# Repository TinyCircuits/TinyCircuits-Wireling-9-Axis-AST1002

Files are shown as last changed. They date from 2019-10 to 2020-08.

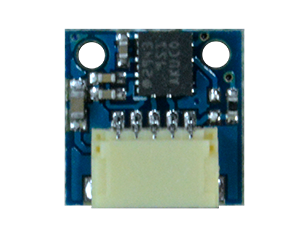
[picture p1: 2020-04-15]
images/AST1002-Learn-Photo-01.png

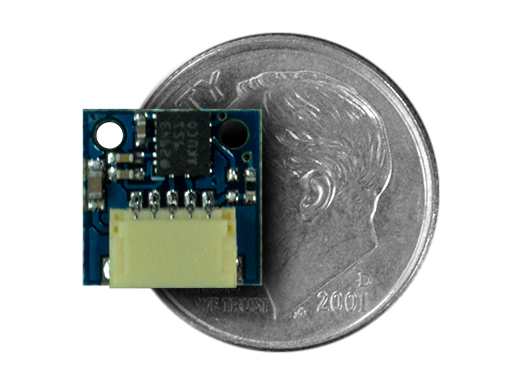
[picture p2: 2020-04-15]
images/AST1002-Product-Photo-03.png

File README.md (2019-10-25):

# TinyCircuits Wireling 9-Axis
# AST1002 Rev1

The design files are located under design_files/ for the TinyCircuits AST1002 Rev 1 PCB. This is a Wireling board which measures 9 degrees of freedom (9DOF) and features the ST LSM9DS1 - a system-in-package featuring a 3D digital linear acceleration sensor, a 3D digital angular rate sensor, and a 3D digital magnetic sensor.

Format is in Cadsoft Eagle format - Eagle version 6.2 was used for the original design.

For more infomation on this, check out the product page at TinyCircuits.com

# License:

Design by TinyCircuits.
All design files are released under the Creative Commons Attribution Share-Alike 3.0 License, see the following link for details: http://creativecommons.org/licenses/by-sa/3.0

All text above must be included in any redistribution or derived design

This project uses designs and concepts developed as part of the Arduino project and the LilyPad project.  The TinyCircuits design files themselves (schematics, PCB and libraries) are not directly derived from these works' design files and have been created new, however the concepts and basic architecture behind the TinyDuino and TinyLily products are derived and we thank the hard work of the organizations below for their contributions to open-source hardware:
  
Original Arduino Uno Design by Team Arduino

LilyPad Arduino Design by Leah Buechley and Sparkfun Electronics

Please support the open-source hardware community

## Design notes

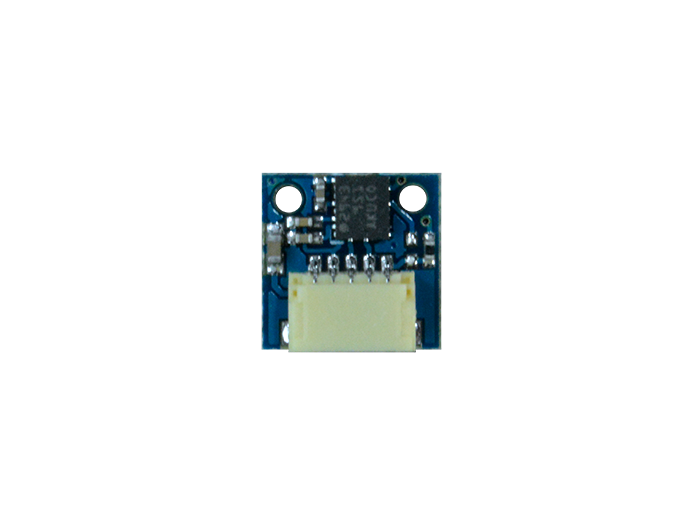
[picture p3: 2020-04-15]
images/AST1002-Product-Photo-01.png

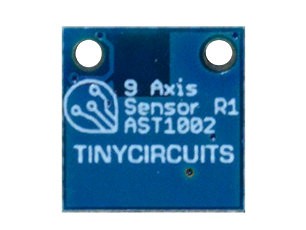
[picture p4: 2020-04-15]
images/AST1002-Learn-Photo-02.png

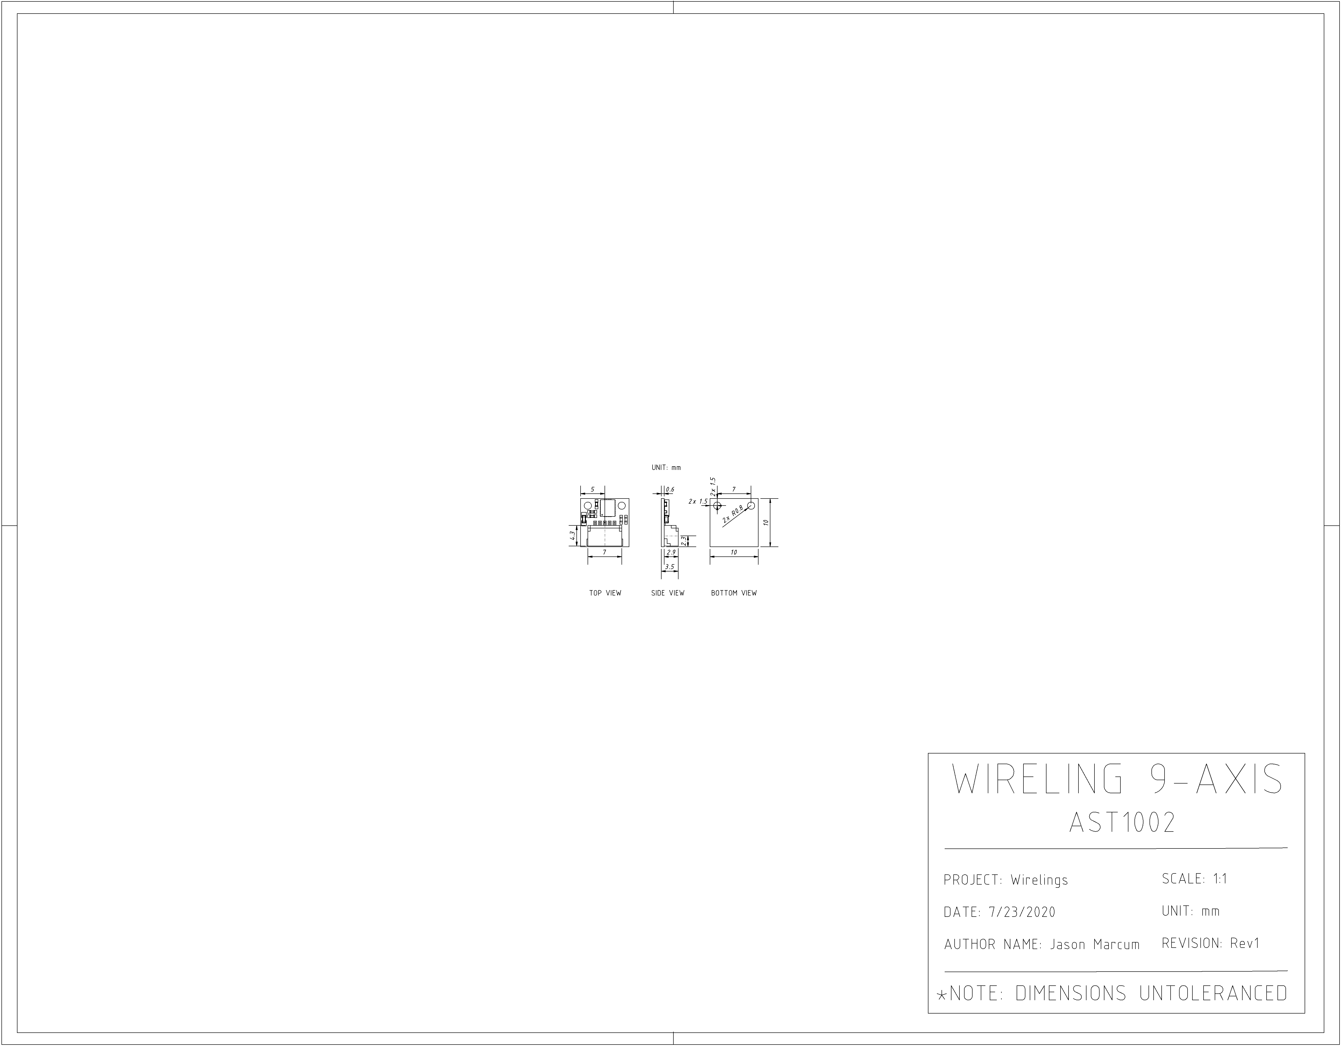
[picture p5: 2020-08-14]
cad/Wireling_9AXIS_AST1002_REV1-DETAILED_DRAWING-PNG.png

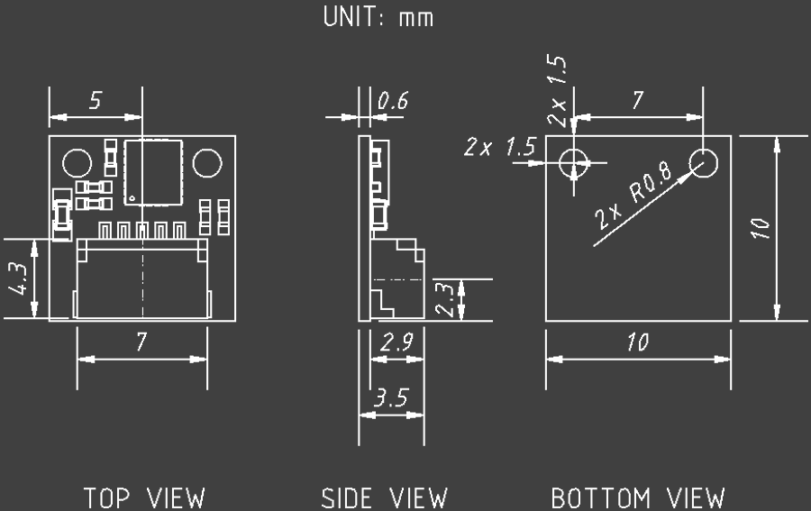
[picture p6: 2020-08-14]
cad/Wireling_9AXIS_AST1002_REV1-DETAILED_DRAWING_COMPACT-PNG.png

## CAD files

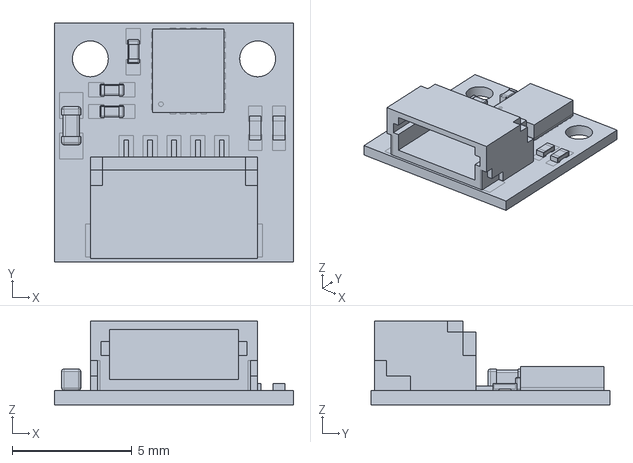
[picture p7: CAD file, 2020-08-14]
cad/Wireling_9AXIS_AST1002_REV1-IGES.iges
10.0 x 10.0 x 3.50 mm

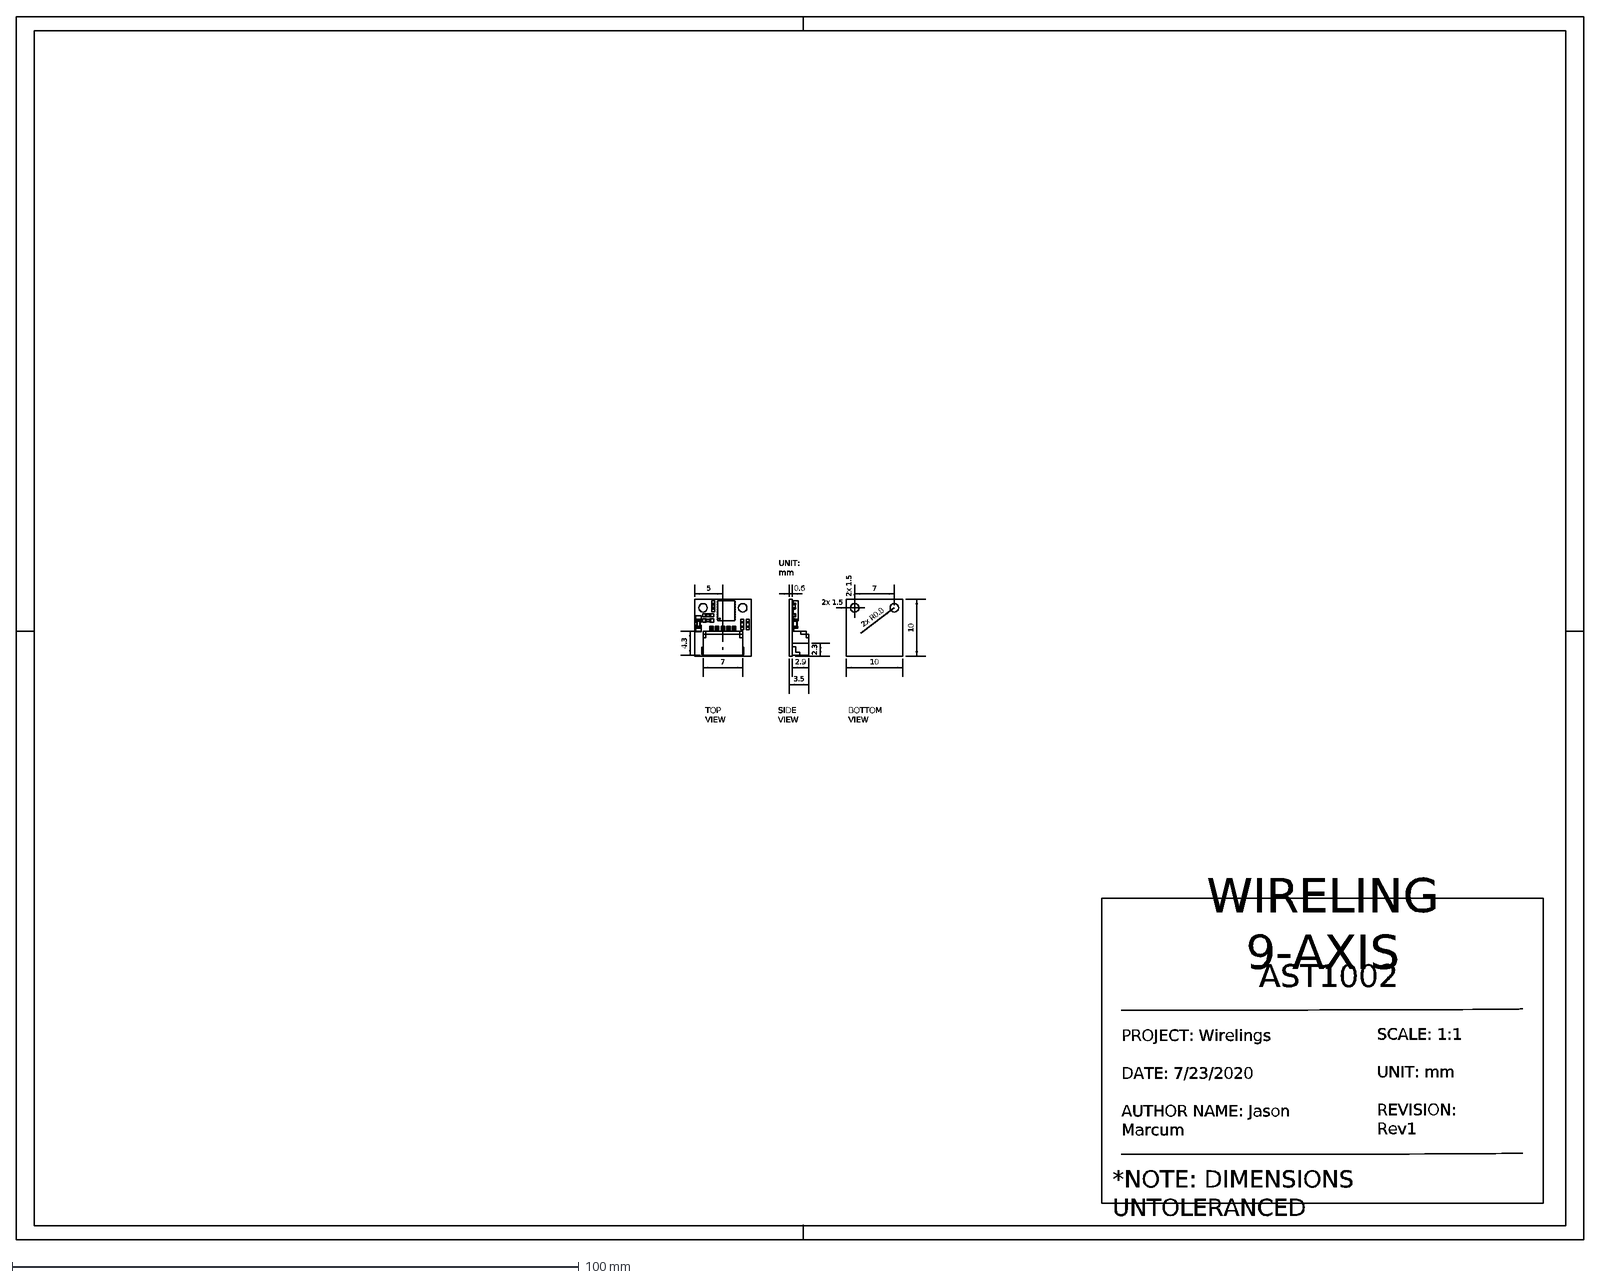
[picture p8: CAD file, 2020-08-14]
cad/Wireling_9AXIS_AST1002_REV1-DETAILED_DRAWING-DXF.dxf
*NOTE: DIMENSIONS UNTOLERANCED
SCALE: 1:1 UNIT: mm REVISION: Rev1
TOP VIEW
BOTTOM VIEW
SIDE VIEW
UNIT: mm
7
4.3
5
2.9
3.5
2.3
0.6
2x 1.5
2x R0.8
10
WIRELING 9-AXIS
AST1002
PROJECT: Wirelings DATE: 7/23/2020 AUTHOR NAME: Jason Marcum

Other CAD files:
cad/Wireling_9AXIS_AST1002_REV1-STL.stl
cad/Wireling_9AXIS_AST1002_REV1-STEP.step

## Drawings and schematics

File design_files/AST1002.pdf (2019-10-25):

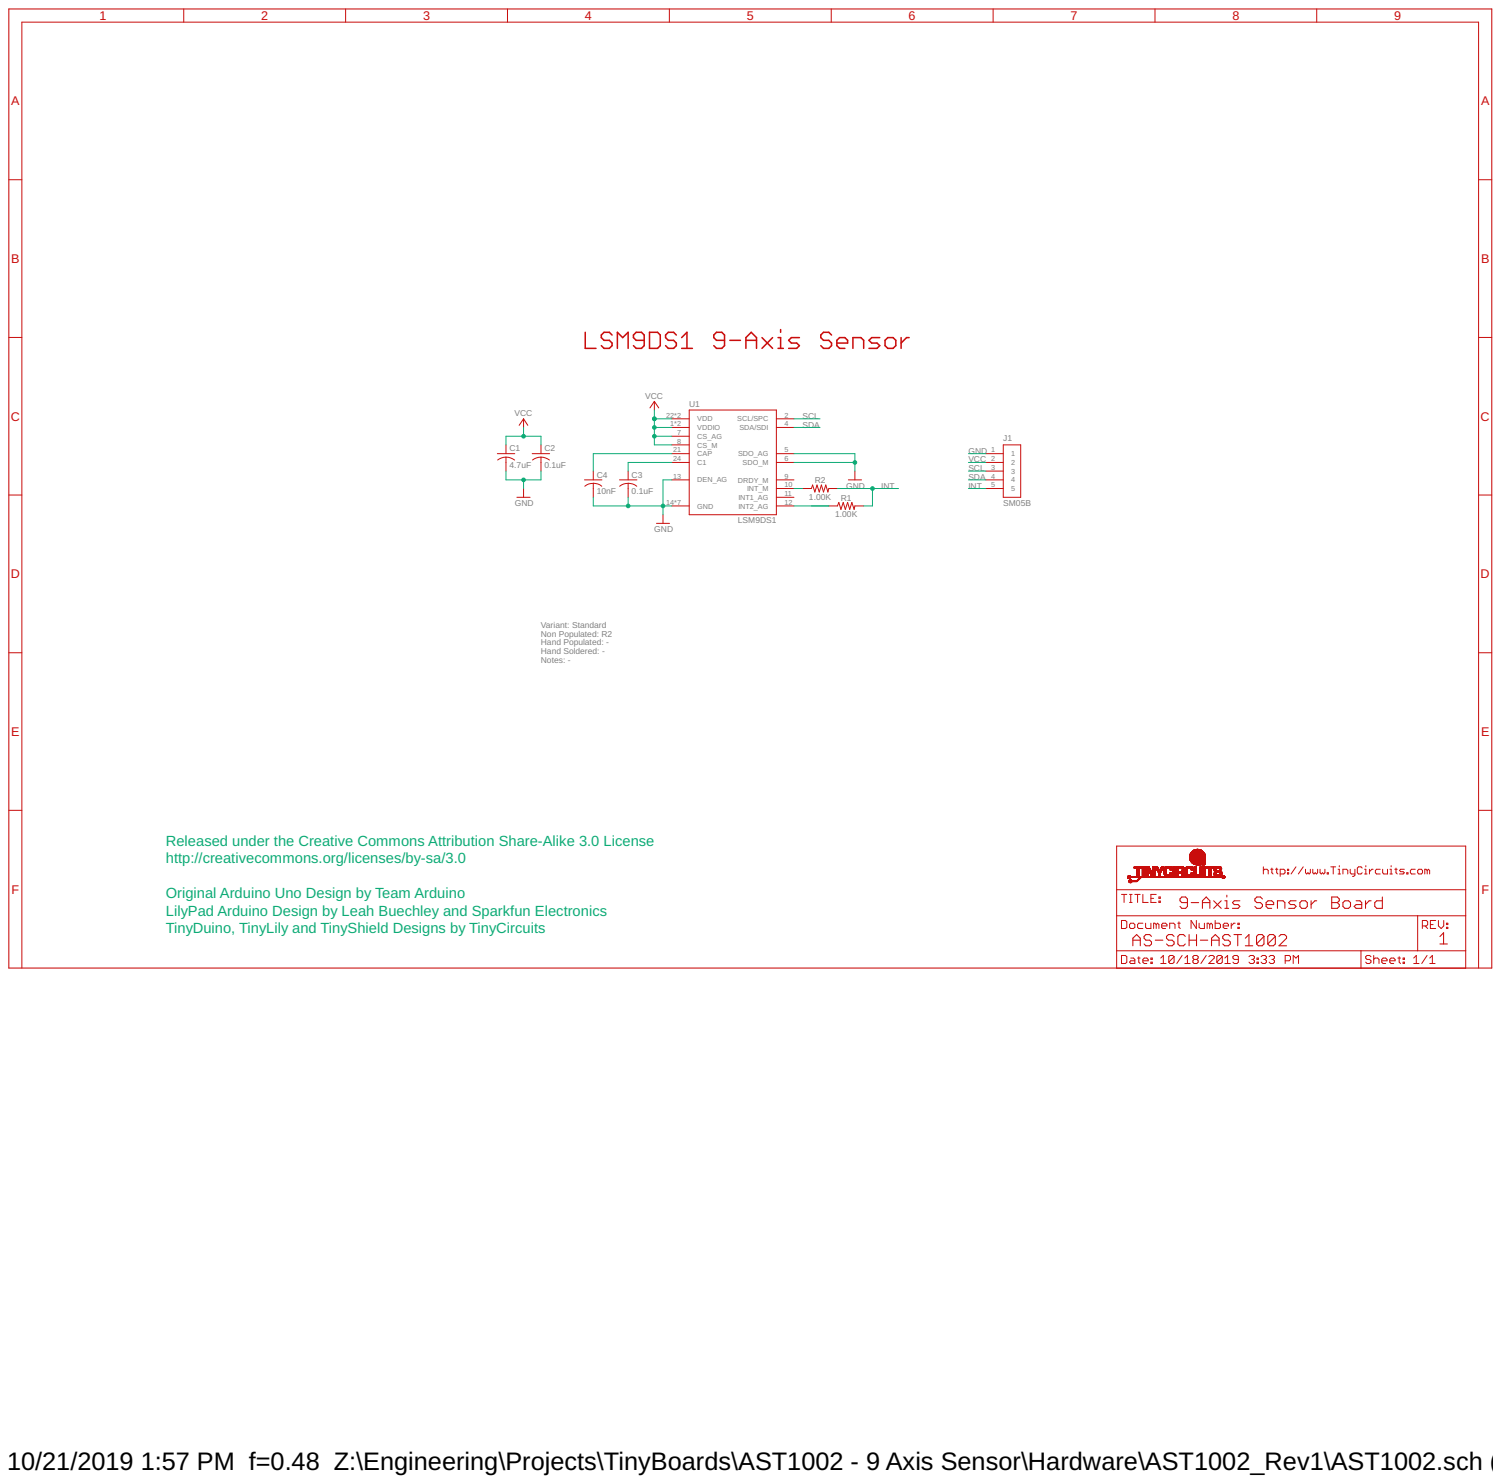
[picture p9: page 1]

Non Populated: R2 Hand Populated: - Hand Soldered: - Variant: Standard Notes: -

Released under the Creative Commons Attribution Share-Alike 3.0 License
http://creativecommons.org/licenses/by-sa/3.0 Original Arduino Uno Design by Team Arduino TinyDuino, TinyLily and TinyShield Designs by TinyCircuits LilyPad Arduino Design by Leah Buechley and Sparkfun Electronics

10/21/2019 1:57 PM f=0.48 Z:\Engineering\Projects\TinyBoards\AST1002 - 9 Axis Sensor\Hardware\AST1002_Rev1\AST1002.sch (Sheet: 1/1)

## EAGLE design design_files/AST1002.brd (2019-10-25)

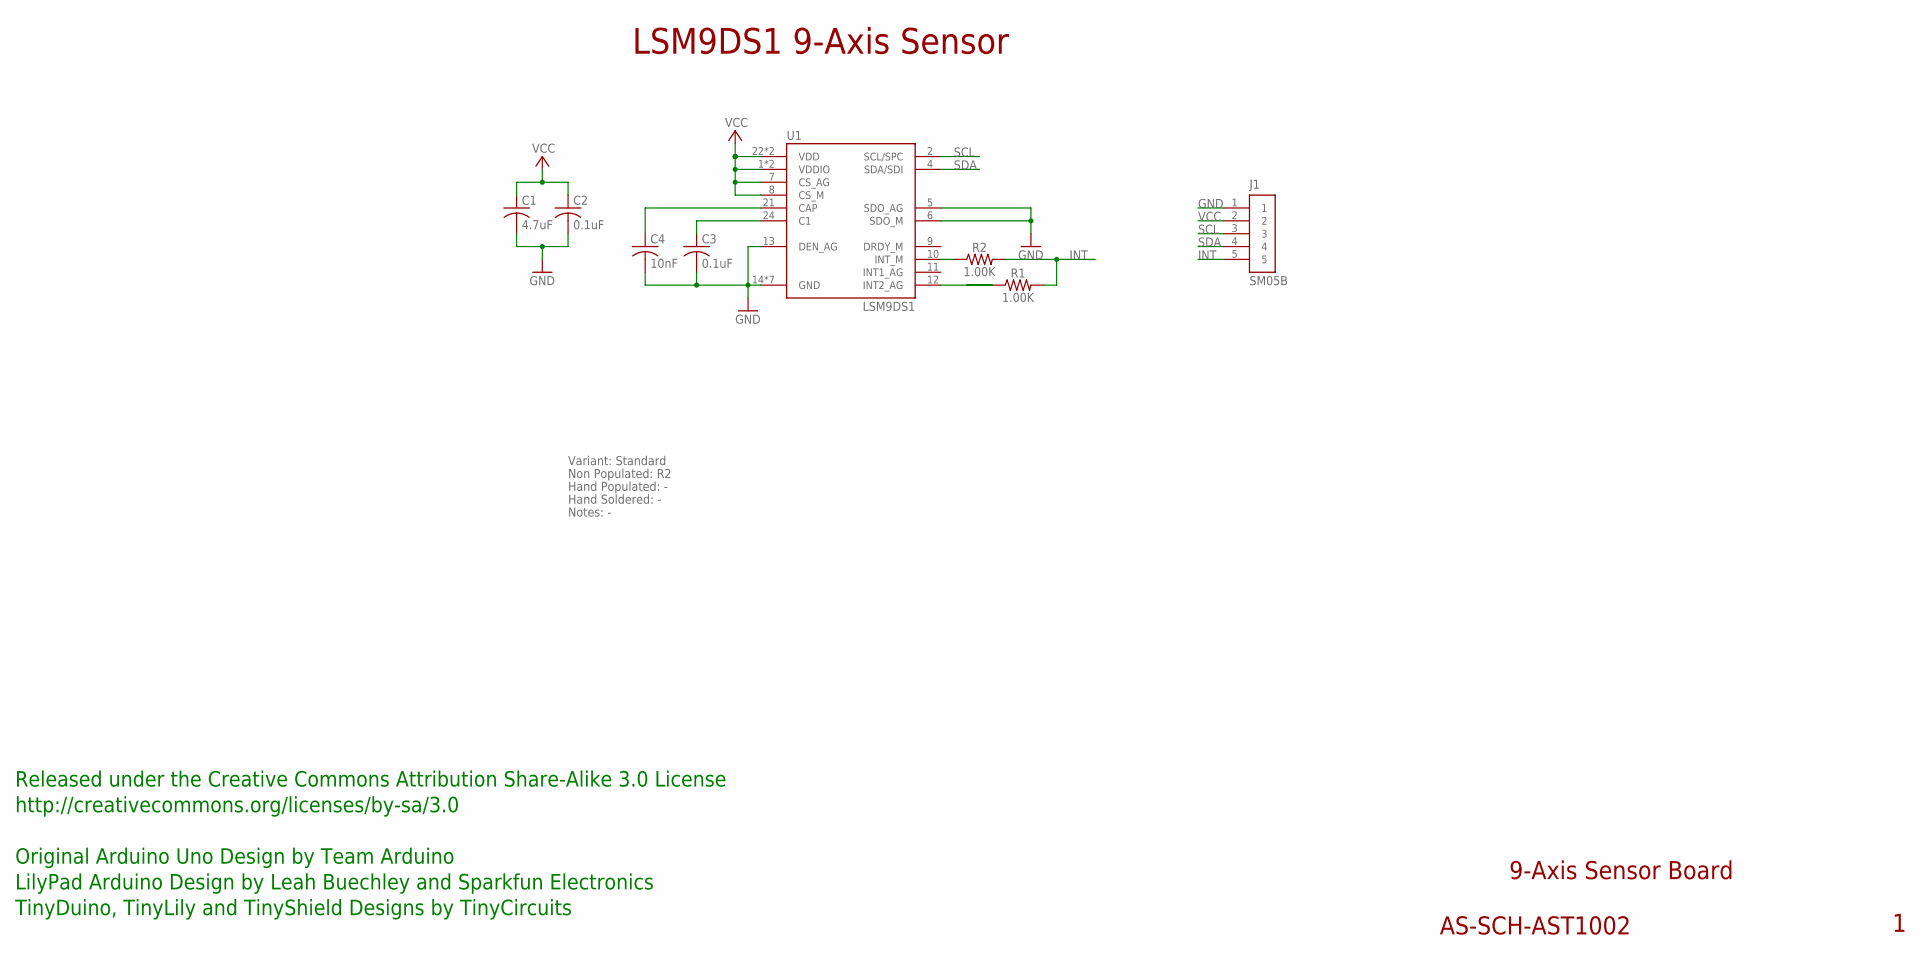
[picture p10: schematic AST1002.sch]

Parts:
C1: 4.7uF; C0603; PARTNO AS-ITM-00088
C2: 0.1uF; C0402
C3: 0.1uF; C0402; PARTNO AS-ITM-00008
C4: 10nF; C0402
J1: SM05B; JST_SH_5X1_EDGE
R1, R2: 1.00K; 0402; PARTNO AS-ITM-00003
U1: LSM9DS1; LGA-24

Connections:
GND: C1.2, C2.2, C3.2, C4.2, J1.1, U1.5 (SDO_AG), U1.6 (SDO_M), U1.13 (DEN_AG), U1.14 (GND), U1.15 (GND), U1.16 (GND), U1.17 (GND), U1.18 (GND), U1.19 (GND), U1.20 (GND)
INT: J1.5, R1.2, R2.2
unnamed: R1.1, U1.12 (INT2_AG)
unnamed: C3.1, U1.24 (C1)
unnamed: C4.1, U1.21 (CAP)
unnamed: R2.1, U1.10 (INT_M)
SCL: J1.3, U1.2 (SCL/SPC)
SDA: J1.4, U1.4 (SDA/SDI)
VCC: C1.1, C2.1, J1.2, U1.1 (VDDIO), U1.3 (VDDIO), U1.7 (CS_AG), U1.8 (CS_M), U1.22 (VDD), U1.23 (VDD)

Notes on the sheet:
9-Axis Sensor Board
AS-SCH-AST1002
LSM9DS1 9-Axis Sensor
Released under the Creative Commons Attribution Share-Alike 3.0 License
http://creativecommons.org/licenses/by-sa/3.0
Original Arduino Uno Design by Team Arduino
TinyDuino, TinyLily and TinyShield Designs by TinyCircuits
LilyPad Arduino Design by Leah Buechley and Sparkfun Electronics
Non Populated: R2
Hand Populated: -
Hand Soldered: -
Variant: Standard
Notes: -

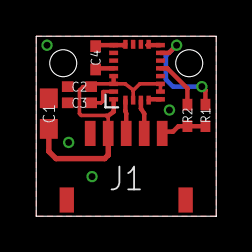
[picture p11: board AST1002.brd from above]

Board: 2 copper layers, 10.0 x 10.0 mm, 9 parts (0 on the bottom side), 9 nets.

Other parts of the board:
U$1: DOCFIELD-TINYCIRCUITS-PCB

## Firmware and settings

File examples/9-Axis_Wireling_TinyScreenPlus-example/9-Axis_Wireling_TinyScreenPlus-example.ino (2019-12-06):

/************************************************************************
 * LSM9SD1 9-Axis Wireling Example:
 * This code has the ability to print out all available values from the 
 * 9 axis sensor, but some are commented out in this Sketch so as not to 
 * over-crowd the Serial Monitor. This program shows the basic methods 
 * on interfacing with this sensor to retrieve value readings. 
 *
 * Hardware by: TinyCircuits
 * Written by: Ben Rose, Lavérena Wienclaw, & Brandon Farmer for TinyCircuits
 *
 * Initiated: 11/20/2017 
 * Updated: 12/06/2019
 ************************************************************************/

#include <Wire.h>            // For I2C connection
#include <Wireling.h>        // For Wireling Interfacing
#include <TinyScreen.h>      // For the TinyScreen+

// For the communication with the LSM9DS1
#include "RTIMUSettings.h"    
#include "RTIMU.h"
#include "RTFusionRTQF.h"

// TinyScreen+ variables
TinyScreen display = TinyScreen(TinyScreenPlus);
int background = TS_16b_Black;

#ifndef ARDUINO_ARCH_SAMD
#include <EEPROM.h>
#endif

RTIMU *imu;                         // the IMU object
RTFusionRTQF fusion;                // the fusion object
RTIMUSettings settings;             // the settings object
int DISPLAY_INTERVAL = 300;         // interval between pose displays

// Global variables to retrieve, store, and schedule readings from the sensor
unsigned long lastDisplay;
unsigned long lastRate;
int sampleCount;
RTVector3 accelData;
RTVector3 gyroData;
RTVector3 compassData;
RTVector3 fusionData; 

// Make Serial Monitor compatible for all TinyCircuits processors
#if defined(ARDUINO_ARCH_AVR)
  #define SerialMonitorInterface Serial
#elif defined(ARDUINO_ARCH_SAMD)
  #define SerialMonitorInterface SerialUSB
#endif


void setup() {
  int errcode;
  SerialMonitorInterface.begin(115200);
  while (!SerialMonitorInterface); // Sensor will not begin printing data until Serial Monitor is opened
  Wire.begin(); // Begin I2C communication

  // Initialize Wireling
  Wireling.begin();
  Wireling.selectPort(0); 

  // TinyScreen appearance variables
  display.begin();
  display.setBrightness(15);
  display.setFlip(true);
  display.setCursor(0, 0);
  display.fontColor(TS_8b_White, TS_8b_Black);
  display.setFont(thinPixel7_10ptFontInfo);
  display.print("9-Axis Test");

  Wireling.selectPort(0); //9-Axis Sensor Port, may differ for you

  imu = RTIMU::createIMU(&settings);        // create the imu object

  SerialMonitorInterface.print("ArduinoIMU begin using device "); SerialMonitorInterface.println(imu->IMUName());
  if ((errcode = imu->IMUInit()) < 0) {
    SerialMonitorInterface.print("Failed to init IMU: "); SerialMonitorInterface.println(errcode);
  }

  // See line 69 of RTIMU.h for more info on compass calibaration 
  if (imu->getCalibrationValid())
    SerialMonitorInterface.println("Using compass calibration");
  else
    SerialMonitorInterface.println("No valid compass calibration data");

  lastDisplay = lastRate = millis();
  sampleCount = 0;

  // Slerp power controls the fusion and can be between 0 and 1
  // 0 means that only gyros are used, 1 means that only accels/compass are used
  // In-between gives the fusion mix.
  fusion.setSlerpPower(0.02);

  // use of sensors in the fusion algorithm can be controlled here
  // change any of these to false to disable that sensor
  fusion.setGyroEnable(true);
  fusion.setAccelEnable(true);
  fusion.setCompassEnable(true);
}

void loop() {
  unsigned long now = millis();
  unsigned long delta;

  if (imu->IMURead()) {     // get the latest data if ready 
    fusion.newIMUData(imu->getGyro(), imu->getAccel(), imu->getCompass(), imu->getTimestamp());
    sampleCount++;
    if ((delta = now - lastRate) >= 1000) {
      SerialMonitorInterface.print("Sample rate: "); SerialMonitorInterface.print(sampleCount);
      if (imu->IMUGyroBiasValid()) {
        SerialMonitorInterface.println(", gyro bias valid");
      }
      else {
        SerialMonitorInterface.println(", calculating gyro bias - don't move IMU!!");
      }

      sampleCount = 0;
      lastRate = now;
    }
    if ((now - lastDisplay) >= DISPLAY_INTERVAL) {
      lastDisplay = now;

      // Get updated readings from sensor and update those values in the 
      // respective RTVector3 object
      accelData = imu->getAccel();
      gyroData = imu->getGyro();
      compassData = imu->getCompass();
      fusionData = fusion.getFusionPose();

      // Acceleration data
      displayScreenAxis("Accel:", accelData.x(), accelData.y(), accelData.z()); 
      displayAxis("Accel:", accelData.x(), accelData.y(), accelData.z());         

// The following data is commented out for easy reading and you can uncomment it all by 
// highlighting it and using "'Ctrl' + '/'" for windows and "'COMMAND' + '/'" for Mac
//      // Gyro data
//      displayScreenAxis("Gyro:", gyroData.x(), gyroData.y(), gyroData.z()); 
//      displayAxis("Gyro:", gyroData.x(), gyroData.y(), gyroData.z());       
//
//      // Compass data
//      displayScreenAxis("Mag:", compassData.x(), compassData.y(), compassData.z());   
//      displayAxis("Mag:", compassData.x(), compassData.y(), compassData.z());    
//
//      // Fused output
//      displayScreenDegrees("Pose:", fusionData.x(), fusionData.y(), fusionData.z());
//      displayDegrees("Pose:", fusionData.x(), fusionData.y(), fusionData.z());      
      SerialMonitorInterface.println();   
    }
  }
}


// Prints out pieces of different radian axis data to Serial Monitor
void displayAxis(const char *label, float x, float y, float z) {
  SerialMonitorInterface.print(label);
  SerialMonitorInterface.print(" x:"); SerialMonitorInterface.print(x);
  SerialMonitorInterface.print(" y:"); SerialMonitorInterface.print(y);
  SerialMonitorInterface.print(" z:"); SerialMonitorInterface.print(z);
}

// Converts axis data from radians to degrees and prints values to Serial Monitor
void displayDegrees(const char *label, float x, float y, float z) {
  SerialMonitorInterface.print(label);
  SerialMonitorInterface.print(" x:"); SerialMonitorInterface.print(x * RTMATH_RAD_TO_DEGREE);
  SerialMonitorInterface.print(" y:"); SerialMonitorInterface.print(y * RTMATH_RAD_TO_DEGREE);
  SerialMonitorInterface.print(" z:"); SerialMonitorInterface.print(z * RTMATH_RAD_TO_DEGREE);
}

// Prints out pieces of different radian axis data to TinyScreen+
void displayScreenAxis(const char *label, float x, float y, float z) {
  // This will make the screen look a little unsteady but is needed in order
  // to clear old values 
  display.clearScreen();

  display.setCursor(0, 0);
  display.fontColor(TS_8b_White, TS_8b_Black);
  display.print("9-Axis Test");
  
  display.setCursor(0, 16);
  display.print(label); 

  display.fontColor(TS_8b_Red, background);
  display.setCursor(0, 28);
  display.print("X = ");
  display.print(x);

  display.fontColor(TS_8b_Green, background);
  display.setCursor(0, 40);
  display.print("Y = ");
  display.print(y);

  display.fontColor(TS_8b_Blue, background);
  display.setCursor(0, 52);
  display.print("Z = ");
  display.print(z);
}

// Converts axis data from radians to degrees and prints values to TinyScreen+
void displayScreenDegrees(const char *label, float x, float y, float z) {
   // This will make the screen look a little unsteady but is needed in order
  // to clear old values 
  display.clearScreen();

  display.setCursor(0, 0);
  display.fontColor(TS_8b_White, TS_8b_Black);
  display.print("9-Axis Test"); 
  
  display.setCursor(0, 16);
  display.print(label);

  display.fontColor(TS_8b_Red, background);
  display.setCursor(0, 28);
  display.print("X = ");
  display.print(x * RTMATH_RAD_TO_DEGREE);

  display.fontColor(TS_8b_Green, background);
  display.setCursor(0, 40);
  display.print("Y = ");
  display.print(y * RTMATH_RAD_TO_DEGREE);

  display.fontColor(TS_8b_Blue, background);
  display.setCursor(0, 52);
  display.print("Z = ");
  display.print(z * RTMATH_RAD_TO_DEGREE);
}
